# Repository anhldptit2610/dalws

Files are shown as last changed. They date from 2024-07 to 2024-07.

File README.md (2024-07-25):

# dalws

A portable handheld device.

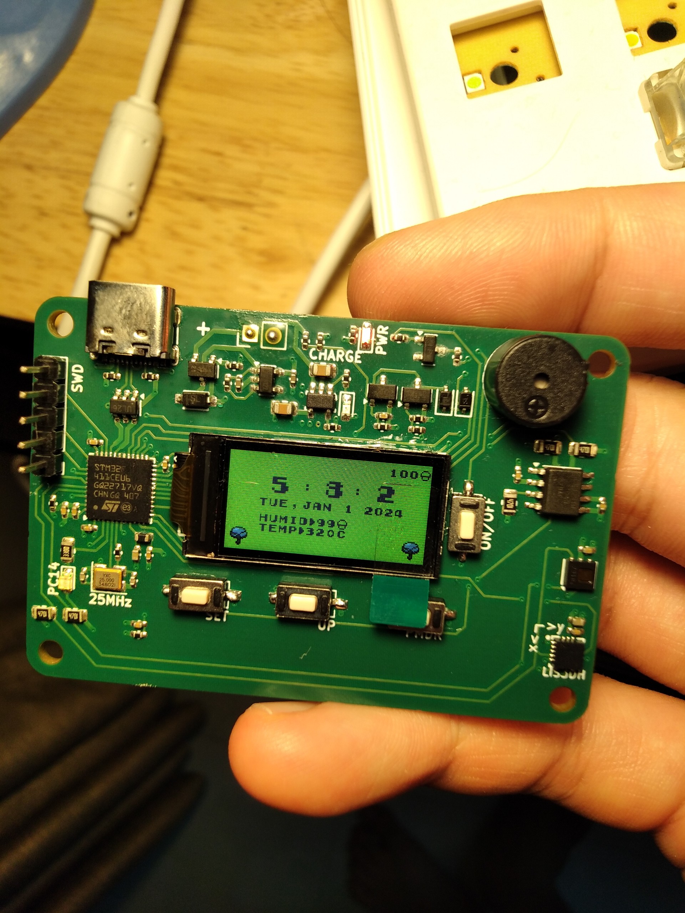
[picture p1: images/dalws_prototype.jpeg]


This project is my attempt to learn about microcontroller and PCB design. Now I realize that making a full, complete
electronic project is **super** hard. I made all the steps in this project, from designing the PCB to program the firmware. To be honest, the PCB design process is harder. Choose components, read the datasheets and lots of schematics, make a design, review and fix errors, quite a lot of work. But it's worth all the pennies and efforts I spent for this project.

## Features

- [x] The MCU: STM32F411CEU6.
- [x] Display the time/date(you can change it of course) on a ST7735's 80x160 screen. The UI is achieved using [LVGL](https://lvgl.io) and [SquareLine's Studio](https://squareline.io)
- [x] Time of day alarm
- [x] Pomodoro timer(I use this a lot. Now only support 25/5/15 format)
- [x] Multiple power source(either USB-C or a LiPo battery. When USB-C and LiPo battery is both present, the USB-C will be chosen. If needed the system will charge the battery, taking power from the USB-C.)

## Demo

See [this](https://www.youtube.com/watch?v=NqJrIAqNZZg)

## How to compile and flash

### Hardware requirements

See [BOM](/docs/bom.xls). The BOM doesn't contain ST7735's LCD screen and buttons.

### Software

 * [SquareLine Studio](https://squareline.io/downloads). It's free for personal use.
 * arm-none-eabi-gcc(my version is 10.3.1)
 * make

You can install above dependencies by using these commands(Ubuntu/any Debian based Linux distro):

    $ sudo apt update
    $ sudo apt install arm-none-eabi-gcc build-essential

### Compiling

    $ git clone --recurse-submodules https://github.com/anhldptit2610/dalws.git
    $ cd dalws/firmware/dalws
    $ make

Use the ST's STM32CubeProgrammer to flash the binary.

## TODO

- [ ] Reduce the size of the PCB(still quite big)
- [ ] Bigger screen so I can have more fun
- [ ] Raise to wake
- [ ] Design a reset mechanism(I whacked a prototype and can't recover just because the design doesn't have a way to reset...)
- [ ] Maybe some games?

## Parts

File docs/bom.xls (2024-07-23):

Comment | Designator | Footprint | JLCPCB Part #
USBLC6-2SC6 | U4 | SOT-23-6 | C2827654
4.7u | C19,C20 | 0805 | C1779
330 | R16 | 0402 | C25104
470 | R22 | 0402 | C25117
MMBT2222A1P | Q5 | SOT-23 | C8512
10k | R15,R9 | 0402 | C25744
100k | R1,R13,R2,R4,R7 | 0402 | C25741
LIS3DH | U3 | LIS3DHTR | C15134
AO3401A | Q1,Q2 | SOT-23 | C15127
KT-0603R | D1,D4 | 0603 | C2286
4.7k | R10,R11,R18,R19,R20 | 0805 | C17673
10u | C11,C9 | 0402 | C15525
25MHz | Y1 | Crystal_SMD_3225-4Pin_3.2x2.5mm | C9006
1u | C14,C15 | 0402 | C52923
KT-0805G | D5 | 0603 | C2297
15p | C10,C4 | 0402 | C1548
MCP73831T-2ACI/OT | U5 | SOT-753 | C424093
1k | R12,R17 | 0402 | C11702
1N5819WS | D2,D6 | D_SOD-323 | C191023
USBC | J1 | USB_C_Receptacle_G-Switch_GT-USB-7010ASV | C2988369
AO3400A | Q3 | SOT-23 | C20917
100n | C13,C16,C17,C2,C1,C12,C18,C22,C3,C5,C6,C7,C8 | 0402 | C1525
5k1 | R5,R6 | 0402 | C25905
AP2112K-3.3 | U1 | SOT-23-5 | C3021085
BLM18AG601SN1D | FB2 | 0603 | C1002
2k | R21 | 0402 | C4109
STM32F411CEUx | U8 | QFN-48-1EP_7x7mm_P0.5mm_EP5.6x5.6mm | C60420
DS3231MZ+TRL | U2 | SOIC-8_3.9x4.9mm_P1.27mm | C107410
1M | R3 | 0402 | C26083
22 | R14 | 0402 | C25092
B5819W | D3 | B5819W | C8598
0 | R8 | 0402 | C17168
330 | R24 | 0805 | C17630
HDC1080 | U6 | Texas_PWSON-N6 | C2864159

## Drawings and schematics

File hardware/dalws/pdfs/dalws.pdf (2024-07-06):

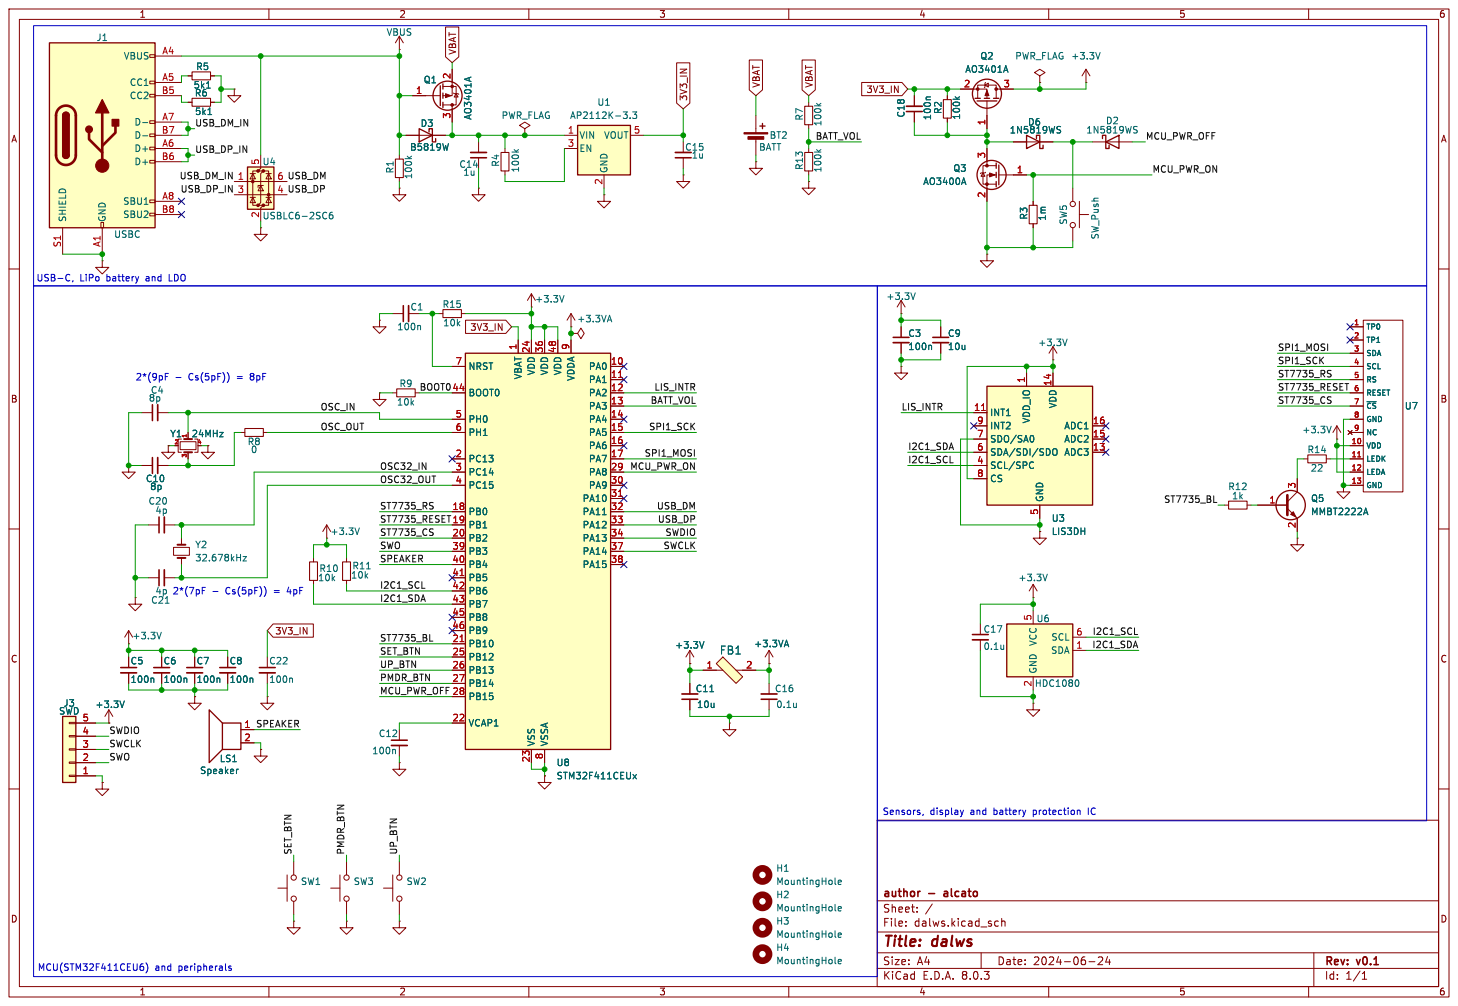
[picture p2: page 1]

USB-C, LiPo battery and LDO

1 PA0 10 PA1 11 PA2 12 PA3 13 PA4 14 PA5 15 PA6 16 PA7 17 PB0 18 PB1 19 PC13 2 PB2 20 PB10 21 VCAP1 22 VSS 23 VDD 24 PB12 25 PB13 26 PB14 27 PB15 28 PA8 29 PC14 3 PA9 30 PA10 31 PA11 32 PA12 33 PA13 34 VDD 36 PA14 37 PA15 38 PB3 39 PC15 4 PB4 40 PB5 41 PB6 42 PB7 43 BOOT0 44 PB8 45 PB9 46 VDD 48 PH0 5 PH1 6 NRST 7 VSSA

LEDA 12 GND 13 TP1 2 SDA 3 SCL 4 RS 5 RESET 6 ~{CS} 7 GND 8 NC 9 U3

5 SDA/SDI/SDO 6 SDO/SA0 7 CS 8

File: dalws.kicad_sch Sheet: / author - alcato

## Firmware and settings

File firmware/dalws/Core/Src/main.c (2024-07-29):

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
/* Includes ------------------------------------------------------------------*/
#include "main.h"

/* USER CODE BEGIN Includes */
#include "hdc1080.h"
#include "ds3231.h"
#include "lvgl.h"
#include "lv_port.h"
#include "ui.h"
#include "display.h"
#include "clock.h"
// #include "hdc1080.h"
/* USER CODE END Includes */

ADC_HandleTypeDef hadc1;

I2C_HandleTypeDef hi2c1;
I2C_HandleTypeDef hi2c3;

SPI_HandleTypeDef hspi1;
DMA_HandleTypeDef hdma_spi1_tx;

TIM_HandleTypeDef htim3;
TIM_HandleTypeDef htim10;
TIM_HandleTypeDef htim11;

/* USER CODE BEGIN PV */
bool state;
ds3231_t ds3231;
char buffer[100];
/* USER CODE END PV */

void SystemClock_Config(void);
static void MX_GPIO_Init(void);
static void MX_DMA_Init(void);
static void MX_I2C1_Init(void);
static void MX_SPI1_Init(void);
static void MX_TIM3_Init(void);
static void MX_TIM10_Init(void);
static void MX_ADC1_Init(void);
static void MX_I2C3_Init(void);
static void MX_TIM11_Init(void);
/* USER CODE BEGIN 0 */

void play_melody(void)
{
  for (int i = 10; i < 30; i++) {
    __HAL_TIM_SET_AUTORELOAD(&htim3, 20 * 2);
    __HAL_TIM_SET_COMPARE(&htim3, TIM_CHANNEL_1, 20);
    HAL_Delay(100);
  }
}

void display_temp_humid(void)
{
  uint16_t tempHumid[2];
  int realTemp, realHumid;
  char str[10];

  hdc1080_get_data(tempHumid);
  realTemp = (tempHumid[0]  * 165) / 65535 - 40;
  lv_snprintf(str, 10, "%d\n", (int)realTemp);
  lv_label_set_text(ui_tempnum, str);
  realHumid = (tempHumid[1]  * 100) / 65536;
  lv_snprintf(str, 10, "%d", (int)realHumid);
  lv_label_set_text(ui_humidnum, str);
}
/* USER CODE END 0 */

/**
  * @brief  The application entry point.
  * @retval int
  */
int main(void)
{
  /* MCU Configuration--------------------------------------------------------*/

  /* Reset of all peripherals, Initializes the Flash interface and the Systick. */
  HAL_Init();

  /* Configure the system clock */
  SystemClock_Config();

  /* Initialize all configured peripherals */
  MX_GPIO_Init();
  MX_DMA_Init();
  MX_I2C1_Init();
  MX_SPI1_Init();
  MX_TIM3_Init();
  MX_TIM10_Init();
  MX_ADC1_Init();
  MX_I2C3_Init();
  MX_TIM11_Init();
  /* USER CODE BEGIN 2 */
  HAL_GPIO_WritePin(MCU_PWR_ON_GPIO_Port, MCU_PWR_ON_Pin, 1);
  HAL_GPIO_WritePin(ST7735_BL_GPIO_Port, ST7735_BL_Pin, 1);
  HAL_GPIO_WritePin(LED_GPIO_Port, LED_Pin, 1);
  state = 1;
  ds3231_init(&hi2c3, &ds3231);
  hdc1080_init(&hi2c1);
  lv_init();
  lv_port_disp_init(&hspi1);
  ui_init();
  clk_init();
  HAL_TIM_Base_Start_IT(&htim10);

  /* USER CODE END 2 */

  /* Infinite loop */
  /* USER CODE BEGIN WHILE */
  while (1)
  {
    /* USER CODE END WHILE */

    /* USER CODE BEGIN 3 */
    lv_timer_handler_run_in_period(5);
    if (state && !HAL_GPIO_ReadPin(MCU_PWR_OFF_GPIO_Port, MCU_PWR_OFF_Pin)) {
      HAL_GPIO_WritePin(LED_GPIO_Port, LED_Pin, 0);
      HAL_Delay(1000);
      if (!HAL_GPIO_ReadPin(MCU_PWR_OFF_GPIO_Port, MCU_PWR_OFF_Pin)) {
        HAL_GPIO_WritePin(LED_GPIO_Port, LED_Pin, 1);
        HAL_GPIO_WritePin(MCU_PWR_ON_GPIO_Port, MCU_PWR_ON_Pin, 0);
      }
    }
  }
  /* USER CODE END 3 */
}

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


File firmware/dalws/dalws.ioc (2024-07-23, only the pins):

Mcu.UserName=STM32F411CEUx
PA1.GPIO_Label=MCU_PWR_ON
PA1.Signal=GPIO_Output
PA13.Signal=SYS_JTMS-SWDIO
PA14.Signal=SYS_JTCK-SWCLK
PA2.GPIO_Label=LIS_INTR
PA2.Signal=GPIO_Input
PA3.Signal=ADCx_IN3
PA5.Signal=SPI1_SCK
PA6.Signal=SPI1_MISO
PA7.Signal=SPI1_MOSI
PA8.Signal=I2C3_SCL
PB0.GPIO_Label=ST7735_RS
PB0.Signal=GPIO_Output
PB1.GPIO_Label=ST7735_RESET
PB1.Signal=GPIO_Output
PB10.GPIO_Label=ST7735_BL
PB10.Signal=GPIO_Output
PB12.GPIO_Label=SET_BTN
PB12.Signal=GPIO_Input
PB13.GPIO_Label=UP_BTN
PB13.Signal=GPIO_Input
PB14.GPIO_Label=PMDR_BTN
PB14.Signal=GPIO_Input
PB15.GPIO_Label=MCU_PWR_OFF
PB15.Signal=GPIO_Input
PB2.GPIO_Label=ST7735_CS
PB2.Signal=GPIO_Output
PB3.Signal=SYS_JTDO-SWO
PB4.Signal=S_TIM3_CH1
PB6.Signal=I2C1_SCL
PB7.Signal=I2C1_SDA
PB8.Signal=I2C3_SDA
PC14-OSC32_IN.GPIO_Label=DS3231_nINT
PC14-OSC32_IN.Signal=GPXTI14
PC15-OSC32_OUT.GPIO_Label=LED
PC15-OSC32_OUT.Signal=GPIO_Output

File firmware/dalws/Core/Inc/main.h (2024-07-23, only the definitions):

#define DS3231_nINT_Pin GPIO_PIN_14
#define DS3231_nINT_GPIO_Port GPIOC
#define DS3231_nINT_EXTI_IRQn EXTI15_10_IRQn
#define LED_Pin GPIO_PIN_15
#define LED_GPIO_Port GPIOC
#define MCU_PWR_ON_Pin GPIO_PIN_1
#define MCU_PWR_ON_GPIO_Port GPIOA
#define LIS_INTR_Pin GPIO_PIN_2
#define LIS_INTR_GPIO_Port GPIOA
#define ST7735_RS_Pin GPIO_PIN_0
#define ST7735_RS_GPIO_Port GPIOB
#define ST7735_RESET_Pin GPIO_PIN_1
#define ST7735_RESET_GPIO_Port GPIOB
#define ST7735_CS_Pin GPIO_PIN_2
#define ST7735_CS_GPIO_Port GPIOB
#define ST7735_BL_Pin GPIO_PIN_10
#define ST7735_BL_GPIO_Port GPIOB
#define SET_BTN_Pin GPIO_PIN_12
#define SET_BTN_GPIO_Port GPIOB
#define UP_BTN_Pin GPIO_PIN_13
#define UP_BTN_GPIO_Port GPIOB
#define PMDR_BTN_Pin GPIO_PIN_14
#define PMDR_BTN_GPIO_Port GPIOB
#define MCU_PWR_OFF_Pin GPIO_PIN_15
#define MCU_PWR_OFF_GPIO_Port GPIOB

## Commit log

2024-07-06 hardware v0.1
    [dalws.kicad_sch]
2024-07-06 use DMA to flush LCD data
2024-07-07 use DMA for LVGL flush callback
2024-07-23 fix ui glitch bugs, HDC1080 works well now
    [bom.xls]
2024-07-23 fix set date issue
    [clock.c]
2024-07-23 LED turns on while pressing off button
2024-07-25 add prototype image, update README

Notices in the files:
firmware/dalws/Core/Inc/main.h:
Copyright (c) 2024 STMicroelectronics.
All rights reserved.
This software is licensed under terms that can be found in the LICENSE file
